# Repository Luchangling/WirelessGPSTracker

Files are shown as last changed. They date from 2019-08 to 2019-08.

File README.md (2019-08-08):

# 项目使用说明
    本项目是深圳市谷米万物科技有限公司自主研发的GW系列超长待机GPS定位器全套原理图、PCB、BOM（在/doc/硬件设计目录下）
    以及应用层源代码等，采用BSD许可协议。任何企业和个人都可以下载、使用或者修改后使用。
    
    项目基于MTK内核开发，/lib/GM_03D_OP_F1提供一个供测试使用的内核库（无法保证大规模使用），如要大规模商用可以联系
    深圳市谷米万物科技有限公司市场部人员索取正式版内核库文件和授权书（内容详见《开源授权书》），下载工具在下面的链接中给出。
    
    编译工具链接：https://pan.baidu.com/s/1ckqe6dtqmJymWbYbLE8zCg 提取码：9bxm 
    APP下载工具链接：https://pan.baidu.com/s/1FpO7Suf3HKmFG9RSkq1bLQ 提取码：pxhs
    内核下载工具链接：https://pan.baidu.com/s/13P_ccS7nhhhhS0J0DI3Q7A 提取码：p4ar 
    以上工具由热心网友提供，建议大家购买正版编译工具和下载工具
    
    测试样机：
    https://detail.m.tmall.com/item.htm?id=588600707880
    https://detail.m.tmall.com/item.htm?id=579762201357

    FAQ文档：
    https://github.com/brucewangzhihua/GPSTracker/blob/master/FAQ.txt

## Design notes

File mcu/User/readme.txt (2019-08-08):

/** @page TIM2_TRIGLSE Generate PWM signal using LSE clock source for TIM2 counter 

  @verbatim
  ******************** (C) COPYRIGHT 2013 STMicroelectronics *******************
  * @file    TIM2/TIM2_TRIGLSE/readme.txt
  * @author  MCD Application Team
  * @version V1.5.2
  * @date    30-September-2014
  * @brief   Description of the TIM2 external trigger mapped to LSE clock Example.
  ******************************************************************************
  *
  * Licensed under MCD-ST Liberty SW License Agreement V2, (the "License");
  * You may not use this file except in compliance with the License.
  * You may obtain a copy of the License at:
  *
  *        http://www.st.com/software_license_agreement_liberty_v2
  *
  * Unless required by applicable law or agreed to in writing, software 
  * distributed under the License is distributed on an "AS IS" BASIS, 
  * WITHOUT WARRANTIES OR CONDITIONS OF ANY KIND, either express or implied.
  * See the License for the specific language governing permissions and
  * limitations under the License.
  *
  ******************************************************************************
   @endverbatim

  @par Example description

  This example explains how to configure TIM2 time base that works completely 
  independently of the system clock. This allows the scheduling of tasks without
  having to take into account the processor state (the processor may be stopped 
  or executing at low or full speed).
  For this purpose, the LSE clock can be internally mapped to the TIM2 ETR input.

  Moreover, this example shows how to configure the TIM2 channel 1 in PWM 
  (Pulse Width Modulation) mode and to be clocked with the LSE clock.
  The TIM2CLK frequency is set to the ETR div 4, the counter prescaler is 1 
  so the TIM2 counter clock is LSE / 4 = 32.768 KHz / 4 = 8.192 KHz.

  The TIM2 period is set to 7, so update event is generated each (7 + 1 ) / 8.192KHz ~ 1 ms
  TIM2 Channel 1 generates a PWM signal with a frequency equal to 1.024 KHz
  TIM2 pulse is set to 4, so the TIM2 Channel 1 generates a PWM signal with 
  a duty cycle equal to 50%:
  TIM2 Channel1 duty cycle = (TIM2 Pulse / (TIM2 Period + 1)) * 100 = 100 * (4 / (7 + 1)) = 50%

  @par Directory contents

  - TIM2/TIM2_TRIGLSE/main.c            Main file containing the "main" function
  - TIM2/TIM2_TRIGLSE/stm8l15x_conf.h   Library Configuration file
  - TIM2/TIM2_TRIGLSE/stm8l15x_it.c     Interrupt routines source
  - TIM2/TIM2_TRIGLSE/stm8l15x_it.h     Interrupt routines declaration

  @par Hardware and Software environment

    - This example runs on STM8L15x High-Density, Medium-Density Plus, Medium-Density
    and Low-Density Devices.

  - This example has been tested with STMicroelectronics STM8L1528-EVAL 
    (STM8L15x High-Density devices) and STM8L1526-EVAL (STM8L15x Medium-Density and
    Low-Density devices) evaluation boards and can be easily tailored to any other
    development board.

  - STM8L1528-EVAL & STM8L1526-EVAL Set-up
    - Make sure that the LCD glass daughter board is mounted in IO position.
      For more details please refer to the evaluation board user manual.
    - Connect TIM2 Channel 1 pin (PB0) to an oscilloscope

  @par How to use it ?

  In order to make the program work, you must do the following :

  - Copy all source files from this example folder to the template folder under
    Project\STM8L15x_StdPeriph_Template
  - Open your preferred toolchain 
  - Rebuild all files and load your image into target memory
  - Run the example

 * <h3><center>&copy; COPYRIGHT STMicroelectronics</center></h3>
 */

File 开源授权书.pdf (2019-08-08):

# 授权书

兹授权： | ，可将我司遵循 BSD 许可协议的开源项

目（该项目是深圳市谷米万物科技有限公司自主研发的 GS03 和 GS05 系列 GPS

定位器全套原理图、PCB、BOM 以及应用层源代码等）应用于商业用途。

在应用我司开源项目于商业用途时，应遵循以下协议要求：

1、一切开源的技术资料包括但不限于源代码、文档、原理图、PCB 等版权

属于深圳市谷米万物科技有限公司；

2、提供的技术资料和源码不保证不存在缺陷，由此造成的一切损失由使用

者承担和负责；

3、使用者必须在产品或者产品包装显眼处标注“本产品由谷米万物提供核

心技术支持”。

授权时间： | ~

深圳市谷米万物科技有限公司（盖章）

日期：

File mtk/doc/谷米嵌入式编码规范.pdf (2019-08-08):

### 一、原则

1. 开放封闭原则：对于扩展是开放的，对于修改是封闭的 (https://www.jianshu.com/p/26c55f40edbd)
2. 单一职责原则：每一个类或者类似的代码块应该只有一个职责，所以只有一个原因会使其改变 (https://www.jianshu.com/p/636d1115eb93)
3. 接口隔离原则：接口尽量细化，同时接口中的方法尽量的少 (https://www.jianshu.com/p/21dfe31ba85b)
4. 最少知道原则：一个对象应该对其他对象保持最少的了解 (https://www.jianshu.com/p/a633e390cf14)
5. 依赖倒置原则：高层模块，低层模块，细节（实现）都应该依赖抽象（即接口） (https://www.jianshu.com/p/314b67f04e50)

## 二、规范

1. 代码文件统一采用GB2312编码，注释中可以使用中文
2. 要解决所有的warning，格式化字符串如果类型不匹配编译器要能够报warning
3. 每一个.c文件应有一个同名.h文件，用于声明需要对外公开的接口，内部需要用到的定义、声明 等放在.c文件中
4. 头文件应当职责单一，尽量少包含其他头文件
5. 头文件应向稳定的方向包含，即应当让不稳定的模块依赖稳定的模块
6. 禁止在头文件中定义变量
7. 函数非空代码行不得超过100行
8. 函数内部要对参数的合法性进行检查
9. 每个函数都要返回错误码，调用程序必须在函数返回时检查错误码
10. 标识符的命名要清晰、明了，有明确含义，使用完整的单词（除非大家基本可以理解的缩 写），尽量避免名字中出现数字编号
11. 类型的命名：大小写字母混用，单词连在一起，每个单词首字母大写
12. 文件名、变量名和函数名：单词用小写字母，每个单词直接用下划线分割
13. 变量名应使用名词或者形容词＋名词方式命名变
14. 函数命名应以函数要执行的动作命名，一般采用动词或者动词＋名词的结构，作为接口的函

### 数名以模块名作为前缀，源文件内部函数名不加前缀，并且要声明为static

15. 宏的命名采用全大写字母，单词之间加下划线，接口文件中的宏名称以GM_开头

### 16. 全局变量应增加“g_”前缀，静态变量应增加“s_”前缀，不用或者少用全局变量和

静态变量，单个文件内部可以使用static的全局变量，可以将其理解为类的私有成员变量

17. 严禁使用未经初始化的变量作为右值，所有变量都要初始化
18. 每个普通变量（整型、字符型）的定义都要考虑范围，严防溢出
19. 每个数组的定义和使用都要严防越界的发生
20. 要尽量避免隐式或者显式的类型转换，防止截断的发生或者符号的丢失
21. 不允许直接使用魔鬼数字
22. 所有的if ... else if结构应该由else子句结束 ；switch语句必须有default分支
23. 程序块采用缩进风格编写，每级缩进为4个空格
24. 相对独立的程序块之间、变量说明之后必须加空行。

25. 多个短语句（包括赋值语句）不允许写在同一行内，即一行只写一条语句
26. if、for、do、while、case、switch、default等语句独占一行
27. 在两个以上的关键字、变量、常量进行对等操作时，它们之间的操作符之前、之后或者前后 要 加空格；进行非对等操作时（如->），后面不应加空格

## 三、注释

1. 文件头部注释：头文件和源文件都要注释，可以使用中文，修改时要一并修改
1 /**
2 * Copyright © Goome Technologies Co., Ltd. 2009‐2019. All right s reserved.
3 | * File name:
4 | * Author: | Version: | Date:
5 | * Description: 用于详细说明此程序文件完成的主要功能，与其他模块或函
数
6 | 的接口，输出值、取值范围、含义及参数间的控制、顺序、独
7 | 立或依赖等关系
8 | * Others:其它内容的说明
9 | * Function List:主要函数列表，每条记录应包括函数名及功能简要说明
10 | 1. ....
11 | * History: 修改历史记录列表，包括修改日期、修改者及修改内容简述
12 | 1. Date:
13 | Author:
14 | Modification:
15 | 2. ...
16 | */
2. 函数注释：函数声明要注释，函数实现不要注释，避免两处不一致 1 /**
2 | * Function: | 函数名称
3 | * Description:函数功能、性能等的描述
4 | * Input: | 输入参数说明，包括每个参数的作用、取值说明及参数间关
系。
5 | * Output: | 对输出参数的说明。
6 | * Return: | 函数返回值的说明
7 | * Others: | 其它说明
8 | */

3. 函数内部注释：函数内部不是注释越多越好，而是变量命名和逻辑清晰，自注释最好，特殊情况 或者需要特别注意的地方才加注释，并且注释要放在代码行的上方，被注释的代码下面要加空行。

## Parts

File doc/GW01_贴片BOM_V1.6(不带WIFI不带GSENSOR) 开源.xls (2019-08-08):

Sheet: GW01 V1.6贴片BOM
 |  |  | GW01 MAIN PCBA物料清单
 |  | 项目负责人 | 邵钢 | BOM版本 | V1.6
 |  | 项目名称 | GW01 | 发行日期 | 2019-08-01
 | 货品代号 | 品名 | 规格 | 数量 | 位号
1 | GM-2302-GW0102-0N8 | PCB | GW01 V1.6/20190214/66.02*35*1.0MM/四层/绿油喷锡镀金
2 | GM-1401-STM8L151C8T6-0N8 | 单片机 | STM8L151C8T6/LQFP48 | 1 | U1
3 | GM-1401-TP2011-000 | 集成IC | TP2011/SOT23-5 | 1 | U3
4 | GM-1401-RT4812-000 | 集成IC | RT4812/TSOT-23-8 | 1 | U6
5 | GM-1401-MT2503-DVB | 基带芯片 | MT2503DV/B | 1 | U30
6 | GM-1401-A6625S-RDA | 射频功放 | RDA6625S | 1 | U300
8 | GM-1401-AT2659-AT0 | GPS | LNA 1559~1610MHz Gain=21.5dB nF=0.8dB 4.3mA | 1 | U4
9 | GM-1401-NFGM003-158 | GPS声表 | DNFH003-1580SA 封装：1109 丝印：H3 支持GPS BD GLONASS三合一 | 1 | SF701
10 | GM-1401-TEA5050-33B | LDO | 3.3V 封装SOT23-5,ETA5050V33S2F,ETA | 1 | U703
12 | GM-0502-000JB0-A00 | 贴片电阻 | 0R/±5%/1/20W/0201 | 4 | R62,R70,L301,R21
13 | GM-0502-330JA0-A00 | 贴片电阻 | 33R/±5%/1/20W 0201 | 2 | R711,R712
14 | GM-0502-101JA0-A00 | 贴片电阻 | 100R/±5%/1/20W/0201 | 5 | R2,R9,R71,R72,R81
15 | GM-0502-511JA0-A00 | 贴片电阻 | 510R/±5%/1/20W/0201 | 1 | R63
16 | GM-0502-102JA0-A00 | 贴片电阻 | 1K/±5% /1/20W 0201 | 7 | R1,R12,R22,R210,R305,R306,R307
17 | GM-0502-152JA0-A00 | 贴片电阻 | 1.5K ±5% 1/20W 0201 | 1 | R221
18 | GM-0502-332JA0-A00 | 贴片电阻 | 3.3K/±5%/1/20W 0201 | 1 | R10
19 | GM-0502-472JA0-A00 | 贴片电阻 | 4.7K/±5%/1/20W/0201 | 3 | R64，R233,R242
20 | GM-0502-562JA0-A00 | 贴片电阻 | 5.6K/±5%/1/20W/0201 | 1 | R15
21 | GM-0502-103JA0-A00 | 贴片电阻 | 10K/±5%/1/20W/0201 | 7 | R60,R61,R65,R101,R209,R308,R709,
22 | GM-0502-203JA0-A00 | 贴片电阻 | 20K/±5%/1/20W/0201 | 2 | R11,R47
23 | GM-0502-243JA0-A00 | 贴片电阻 | 24K/±5%/1/20W 0201 | 1 | R310
24 | GM-0502-393JA0-A00 | 贴片电阻 | 39K/±5%/1/20W 0201 | 1 | R5
26 | GM-0502-913JA0-A00 | 贴片电阻 | 91K ±5% 1/20W 0201 | 1 | R714
27 | GM-0502-104JA0-A00 | 贴片电阻 | 100K/±5%/1/20W 0201 | 4 | R76,R80,R82,R703
28 | GM-0502-104FB0-B00 | 贴片精密电阻 | 100K/±1%/1/16W/0402 | 1 | R78
29 | GM-0502-334FA0-A00 | 贴片精密电阻 | 330K/1%/1/20W 0201 | 1 | R7
30 | GM-0502-7323FB0-B00 | 贴片精密电阻 | 732K/±1%/1/16W/0402 | 1 | R77
31 | GM-0502-124JA0-A00 | 贴片电阻 | 120K ±5% 1/20W 0201 | 1 | R713
32 | GM-0502-105JA0-A00 | 贴片电阻 | 1M/±5%/1/20W/0201 | 1 | R79
33 | GM-0502-565JA0-A00 | 贴片电阻 | 5.6M/±5%/1/20W/0201 | 1 | R68
34 | GM-0502-106JA0-A00 | 贴片电阻 | 10M/±5%/1/20W/0201 | 2 | R66,R67
35 | GM-0602-60FD8B-A05 | 贴片电容 | 6PF/±0.5PF/50V/NPO/0201 | 2 | C3,C68
36 | GM-0602-180J8A-A00 | 贴片电容 | 18pF±5% /50V COG 0201 | 5 | C66,C88,C16,C703,C706
37 | GM-0602-05FC8A-A00 | 贴片电容 | 0.5pF±0.25pF 50V COG 0201 | 1 | L303
38 | GM-0602-12FC8A-A00 | 贴片电容 | 1.2pF±0.25pF 50V COG 0201 | 2 | C339,C724
39 | GM-0602-22FC8A-A00 | 贴片电容 | 2.2pF ±0.25pF 50V COG 0201 | 1 | C332
40 | GM-0602-39FC8A-A00 | 贴片电容 | 3.9PF±0.25PF 50V COG 0201 | 1 | C330
42 | GM-0602-220J8A-A00 | 贴片电容 | 22PF±5% 50V COG 0201 | 4 | C308,C309,C310,C312
43 | GM-0602-330J8A-A00 | 贴片电容 | 33PF±5% 50V COG 0201 | 5 | C1,C2,C7,C316,C342
44 | GM-0602-101J6A-A00 | 贴片电容 | 100pF±5% 25V COG 0201 | 1 | C317
45 | GM-0602-221K8A-A00 | 贴片电容 | 220pF±10% 50V COG 0201 | 1 | C307
46 | GM-0602-221K8D-A00 | 贴片电容 | 220pF±10% 50V X7R 0201
47 | GM-0602-151J8B-B05 | 贴片电容 | 150PF/±5%/50V/NPO/0402 | 1 | C19
48 | GM-0602-511J8B-C05 | 贴片电容 | 510PF/±5%/50V/NPO/0603 | 1 | C30
49 | GM-0602-104K3C-A00 | 贴片电容 | 100NF±10% 10V X5R 0201 | 9 | C12,C21,C22,C35,C60,C62,C65,C67,C732
50 | GM-0602-104M3C-A00 | 贴片电容 | 100NF±20% 10V X5R 0201
51 | GM-0602-102K6D-A00 | 贴片电容 | 1nF±10% 25V X7R 0201 | 4 | C31,C338,C709,C315
52 | GM-0602-102M8D-A00 | 贴片电容 | 1nF±20% 50V X7R 0201
53 | GM-0602-472K4D-A00 | 贴片电容 | 4.7nF±10% 16V X7R 0201 | 3 | C14,C716,C717
54 | GM-0602-104K4C-B05 | 贴片电容 | 100NF/±10%/16V/X5R/0402 | 1 | C6
55 | GM-0602-105K4C-C05 | 贴片电容 | 1UF/±10%/16V/X5R/0603 | 1 | C70
56 | GM-0602-105K2C-A00 | 贴片电容 | 1uF±10% 6.3V X5R 0201 | 33 | C5,C8,C9,C18,C34,C61,C63,C64,C69,C200,C203，C206,C207,C215,C217,C219,C223,C301,C718,C719,C720,C729,C733,C220,C727，C208,C216,C221,C224,C218,C225,C222,C711
57 | GM-0602-105M2C-A00 | 贴片电容 | 1uF±20% 6.3V X5R 0201
58 | GM-0602-225M3C-B00 | 贴片电容 | 2.2uF±20% X5R 10V 0402 | 3 | C205,C728,C730
59 | GM-0602-225M2C-B00 | 贴片电容 | 2.2uF±20% X5R 6.3V 0402
60 | GM-0602-475M2C-B00 | 贴片电容 | 4.7uF±20% X5R 6.3V 0402 | 5 | C213,C721,C722,C723,C726
61 | GM-0602-106K8C-D05 | 贴片电容 | 10UF/±10%/16V/X5R/0805 | 2 | C15,C313
62 | GM-0602-226K2C-D00 | 贴片电容 | 22uF±10% X5R 6.3V 0805 H=0.85mm | 1 | C20
63 | GM-0601-227M20-J07 | 贴片钽电容 | TLJB227M006R0500/220UF/±20%/6.3V/B型 | 2 | EC3,EC2
64 | GM-1100-LMB340-000 | 贴片二极管 | LMBR340/SOD-123 | 1 | D1
65 | GM-1501-000805-000 | 贴片发光二极管 | 白发黄/0805/SMD | 1 | LGPS
66 | GM-1501-G00805-000 | 贴片发光二极管 | 白发绿/0805/SMD | 1 | LGSM
68 | GM-0703-472MD0-006 | 贴片叠层电感 | 4.7uH±20% 0805 500mA | 1 | L707
69 | GM-0701-24FSA0-004 | 贴片叠层电感 | 2.4nH ±0.3NH 0201 | 1 | C328
70 | GM-0701-30FSA0-004 | 贴片电感 | 3.0nH±0.3nH 0201 | 1 | L309
71 | GM-0701-33FSA0-004 | 贴片叠层电感 | 3.3nH ±0.3NH 0201 | 1 | L702
72 | GM-0701-36FSA0-004 | 贴片电感 | 3.6nH±0.3nH 0201 | 2 | C340,C343
73 | GM-0701-47FSA0-004 | 贴片叠层电感 | 4.7nH ±0.3NH 0201 | 1 | C306
74 | GM-0701-68FJA0-004 | 贴片电感 | 6.8NH±5% 0201 | 3 | L2,C318,L308
75 | GM-0701-100JA0-004 | 贴片电感 | 10nH ±5% 0201 | 1 | L4
76 | GM-0701-270JA0-004 | 贴片电感 | 27NH±5% 0201 | 1 | L320
77 | GM-0701-390JA0-004 | 贴片电感 | 39nH±5% 0201 | 1 | C701
79 | GM-0703-152M90-0MT | 贴片电感 | 1.5UH/±20%/7.6*7.0*3.0MM/一体成型/SMD | 1 | L1
80 | GM-1200-L9014Q-001 | 贴片三极管 | L9014QLT1G/SOT-23 | 1 | Q5
81 | GM-1201-SI2305-001 | 贴片MOS管 | SI2305DS/SOT23 | 2 | Q2,Q4
82 | GM-1201-NC3416-001 | 贴片MOS管 | NCE3416/SOT-23 | 1 | Q3
83 | GM-2200-SC32S0-0JG | 贴片晶振 | 32.768khz/3215/12.5 pF/ Q-SC32S03220C5AAAF， | 1 | Y1
84 | GM-2200-X1G004-EPS | 贴片晶振 | 26MHz ±0.5ppm 2520 TCXO 丝印J5，X1G004211000300，EPSON | 1 | Y702
89 | GM-2200-X3S026-HEL | 贴片晶振 | 26MHZ 3.2*2.5mm，X3S026000B71HZ-HPR，加高 | 1 | X301
96 | GM-5303-GW0102-00X | 基带屏蔽罩 | 洋白铜，36*31*2.0mm,GW01基带屏蔽罩,鼎宇五金 | 1
97 | GM-2118-YK56SL-000 | 拨动开关 | YK56-SL（大六角）柄高2.0mm，间距2.5mm/耐高温 | 1 | K1
98 | GM-5416-GW01PG-JXX | 贴片天线顶针 | PG6.7-4.7 Φ=2.0 H=2.0mm | 1 | RF3
99 | GM-2101-1*4PIN-000 | 贴片插座 | 1*4PIN，间距1.0mm/L6.0*H4.5*W3.0mm | 1 | CON1
100 | GM-2105-UPC791-MUP | SIM卡座 | 8PIN Micro-sim Card con,MUP-C791,H=1.5mm | 1 | SIM1

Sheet: 修改记录
日期 | 版本号 | 更改序号 | 更 改 内 容 | 更改人 | 备注

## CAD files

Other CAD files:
mcu/STVP/stvp_download.stp

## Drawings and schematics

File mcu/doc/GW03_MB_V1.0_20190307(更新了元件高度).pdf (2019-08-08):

A

1 | 2 | 3 | 4 | 5 | 6

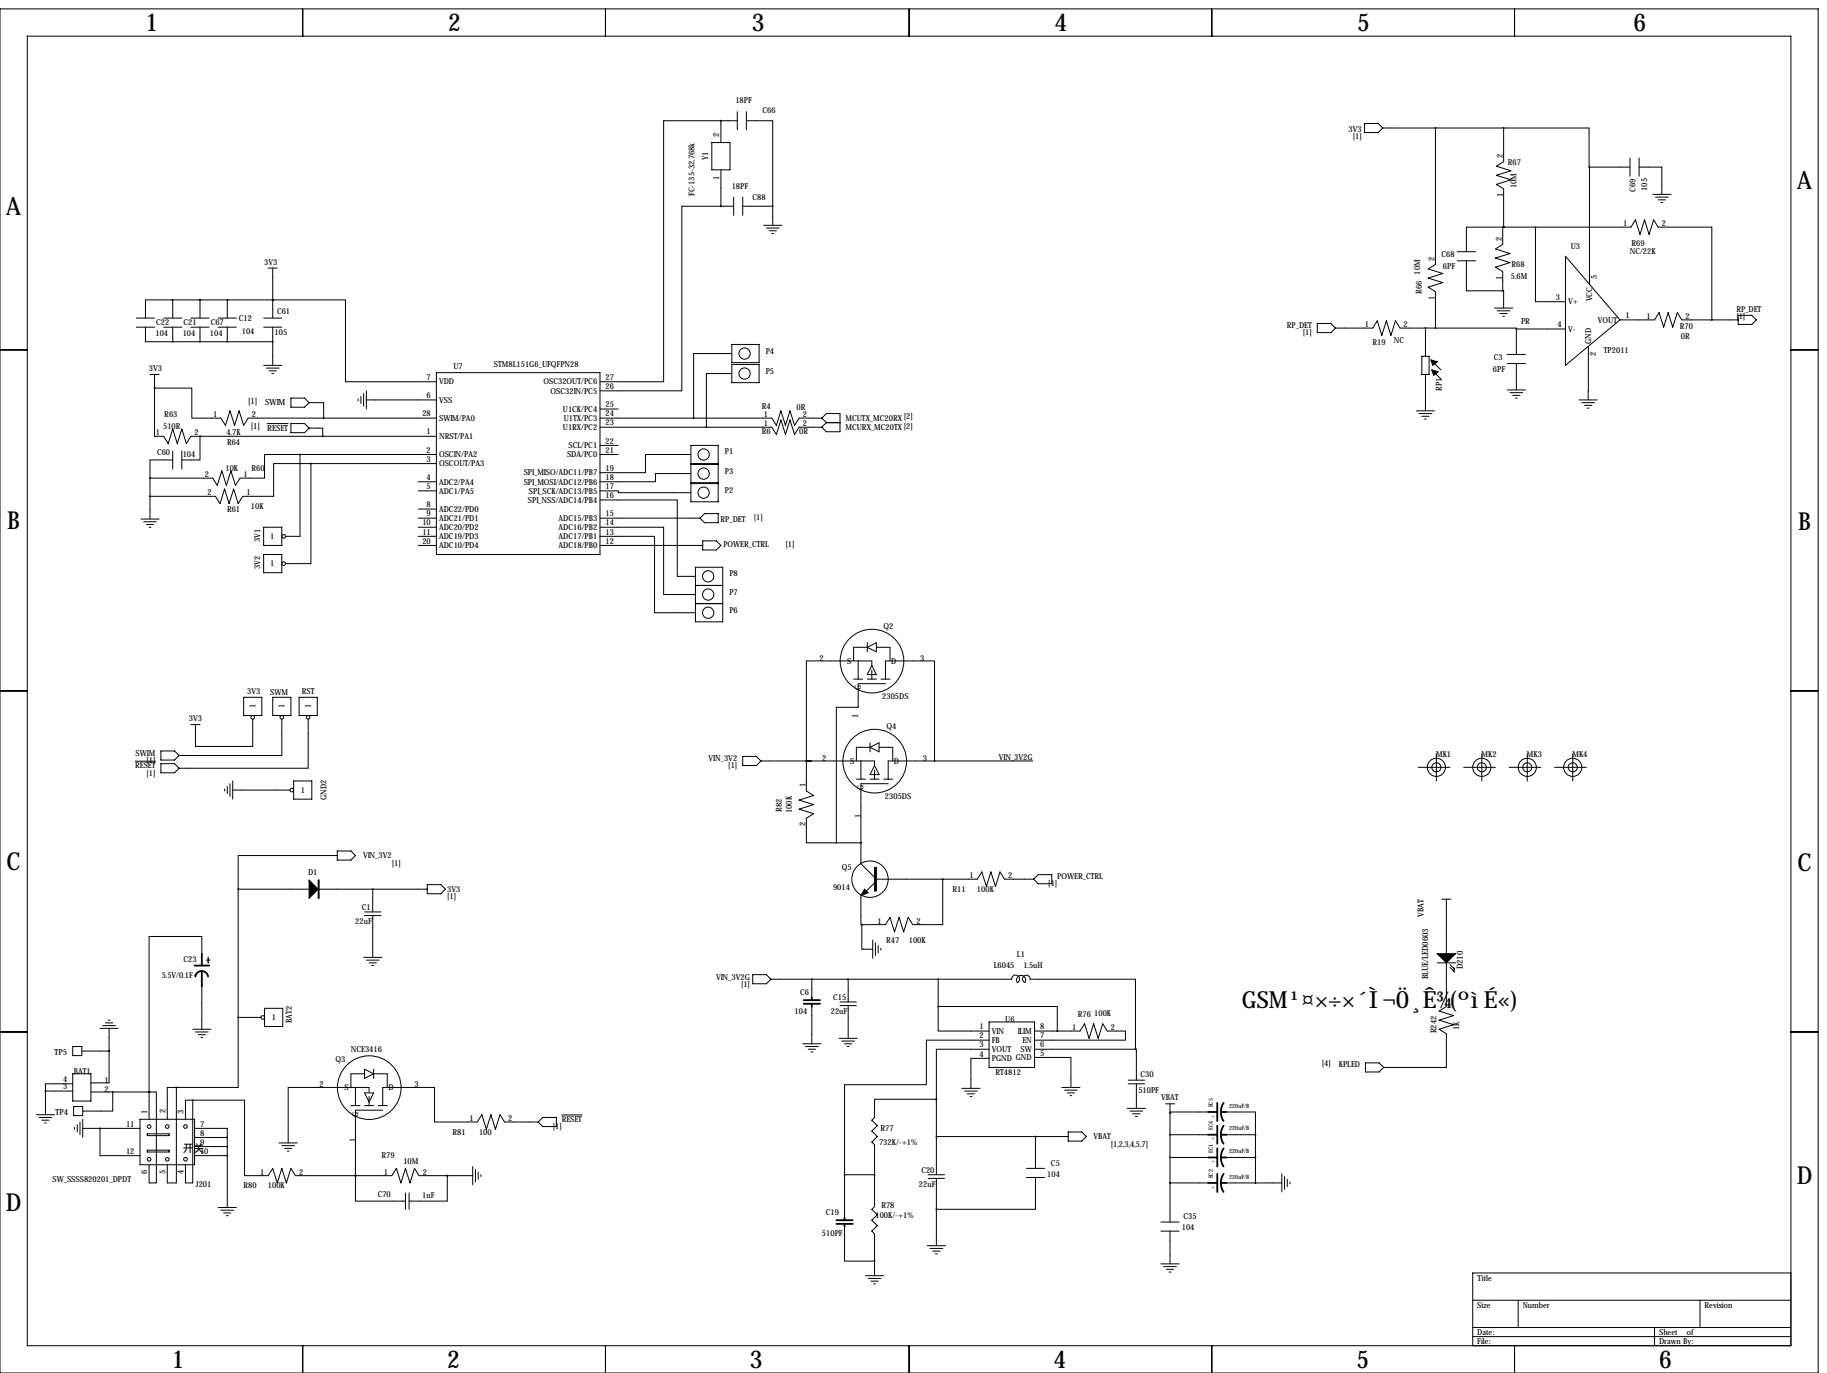
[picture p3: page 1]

OSCIN/PA2 3

ADC2/PA4 5 ADC22/PD0 9

Size | Number | Revision

Date: | Sheet of
File: | Drawn By:

6 | 5 | 4 | 3 | 2 | 1

D

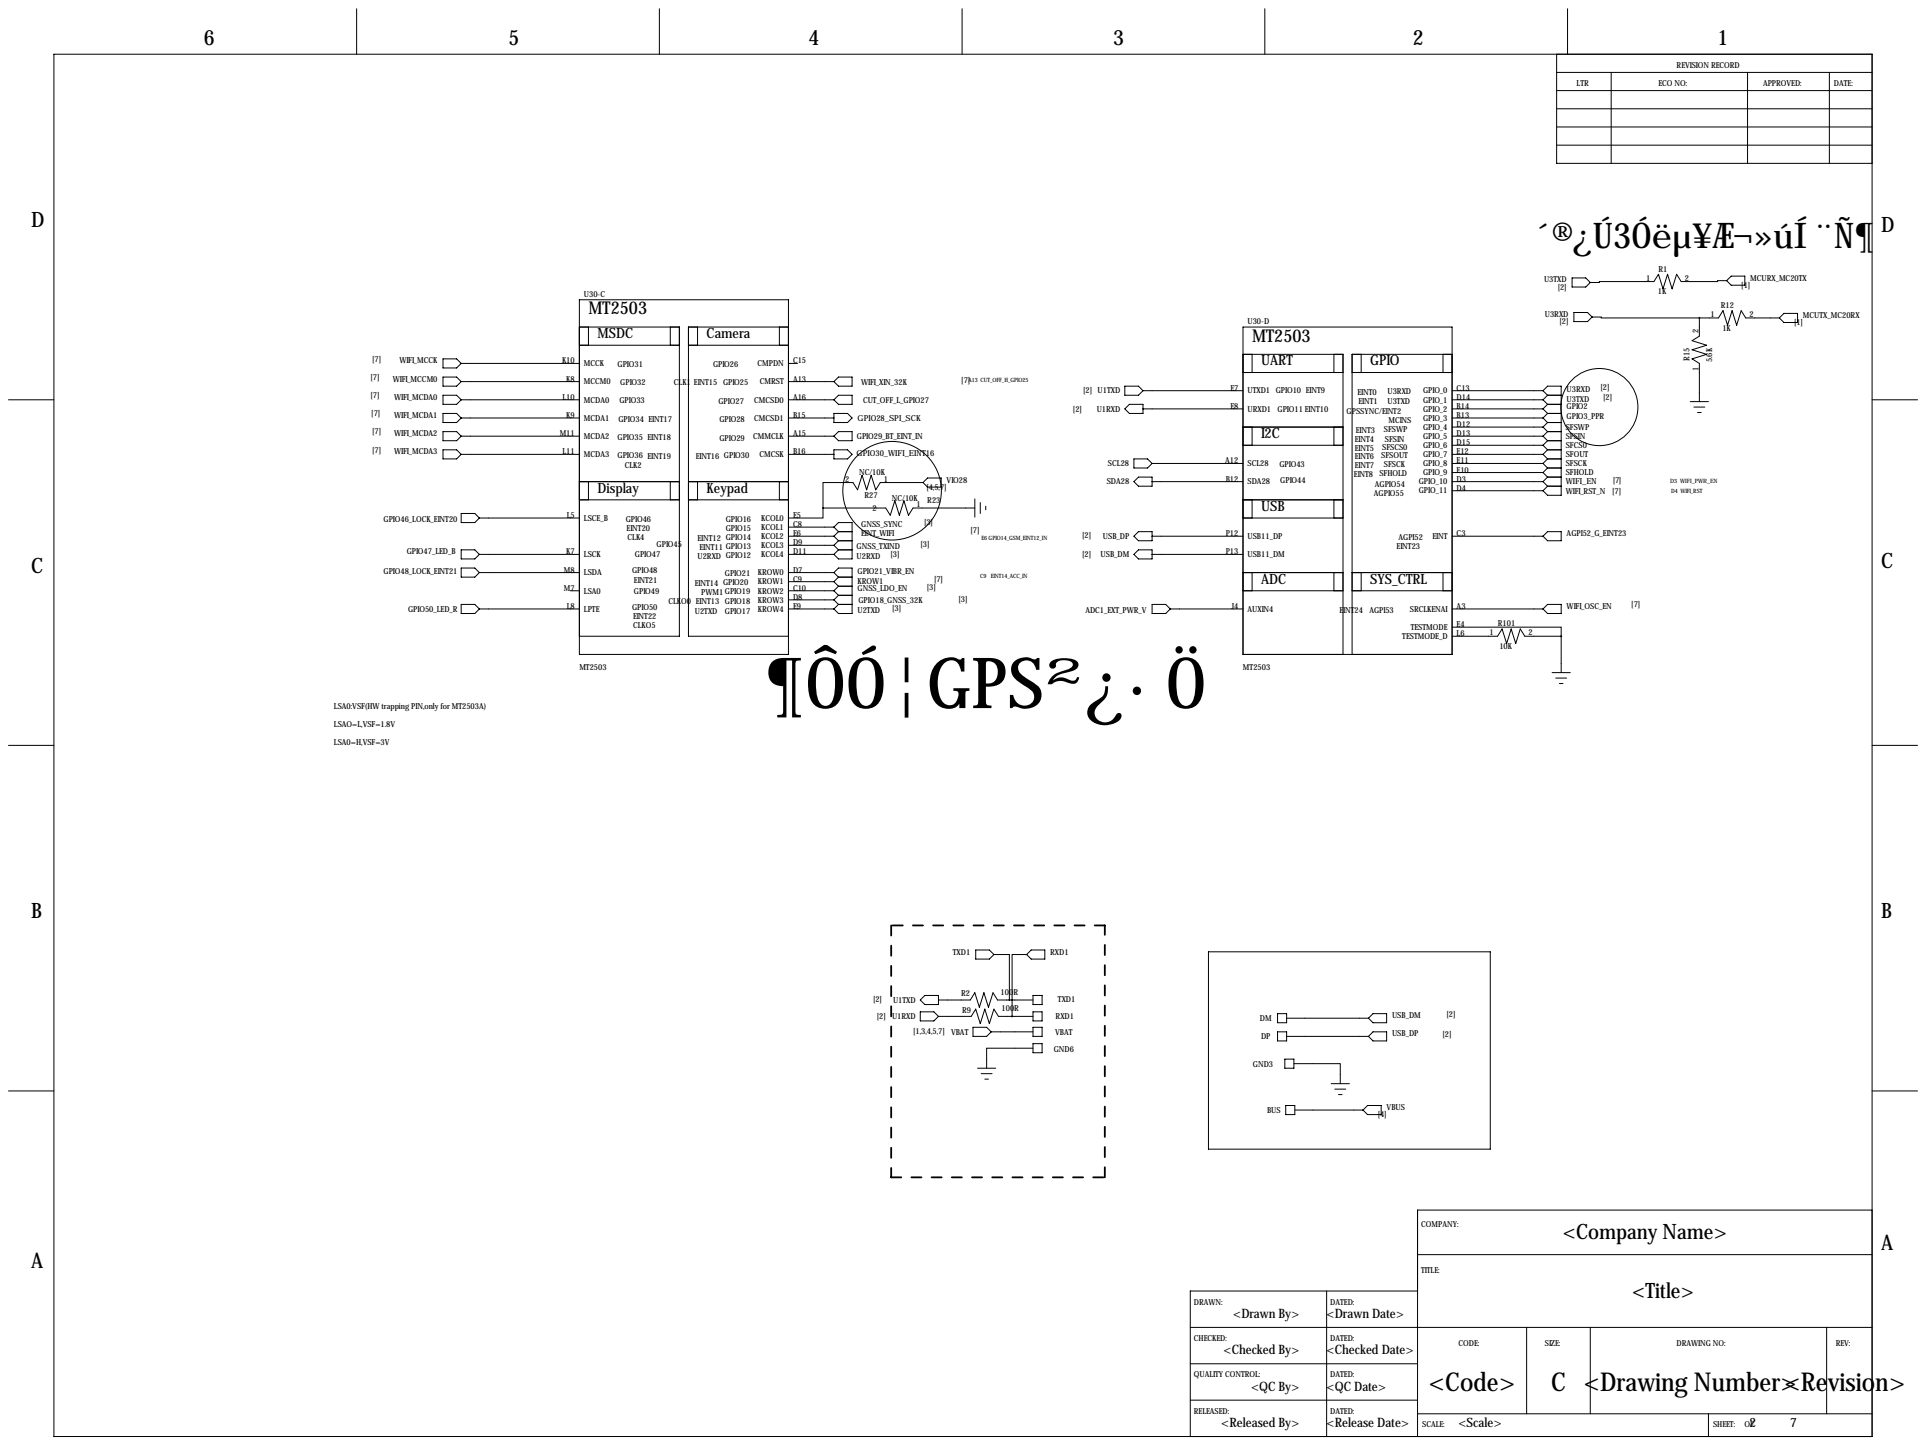
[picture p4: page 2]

U30-C | REVISION RECORD

LTR | ECO NO: | APPROVED: | DATE:

LSA0:VSF(HW trapping PIN,only for MT2503A)

DRAWN: <Drawn By> | DATED: <Drawn Date>

CHECKED: <Checked By> | DATED: <Checked Date> | CODE: | SIZE: | DRAWING NO: | REV:

QUALITY CONTROL: <QC By> | DATED: <QC Date>

RELEASED: <Released By> | DATED: <Release Date>

<Scale> SCALE: | 2 7 SHEET: OF

D
D

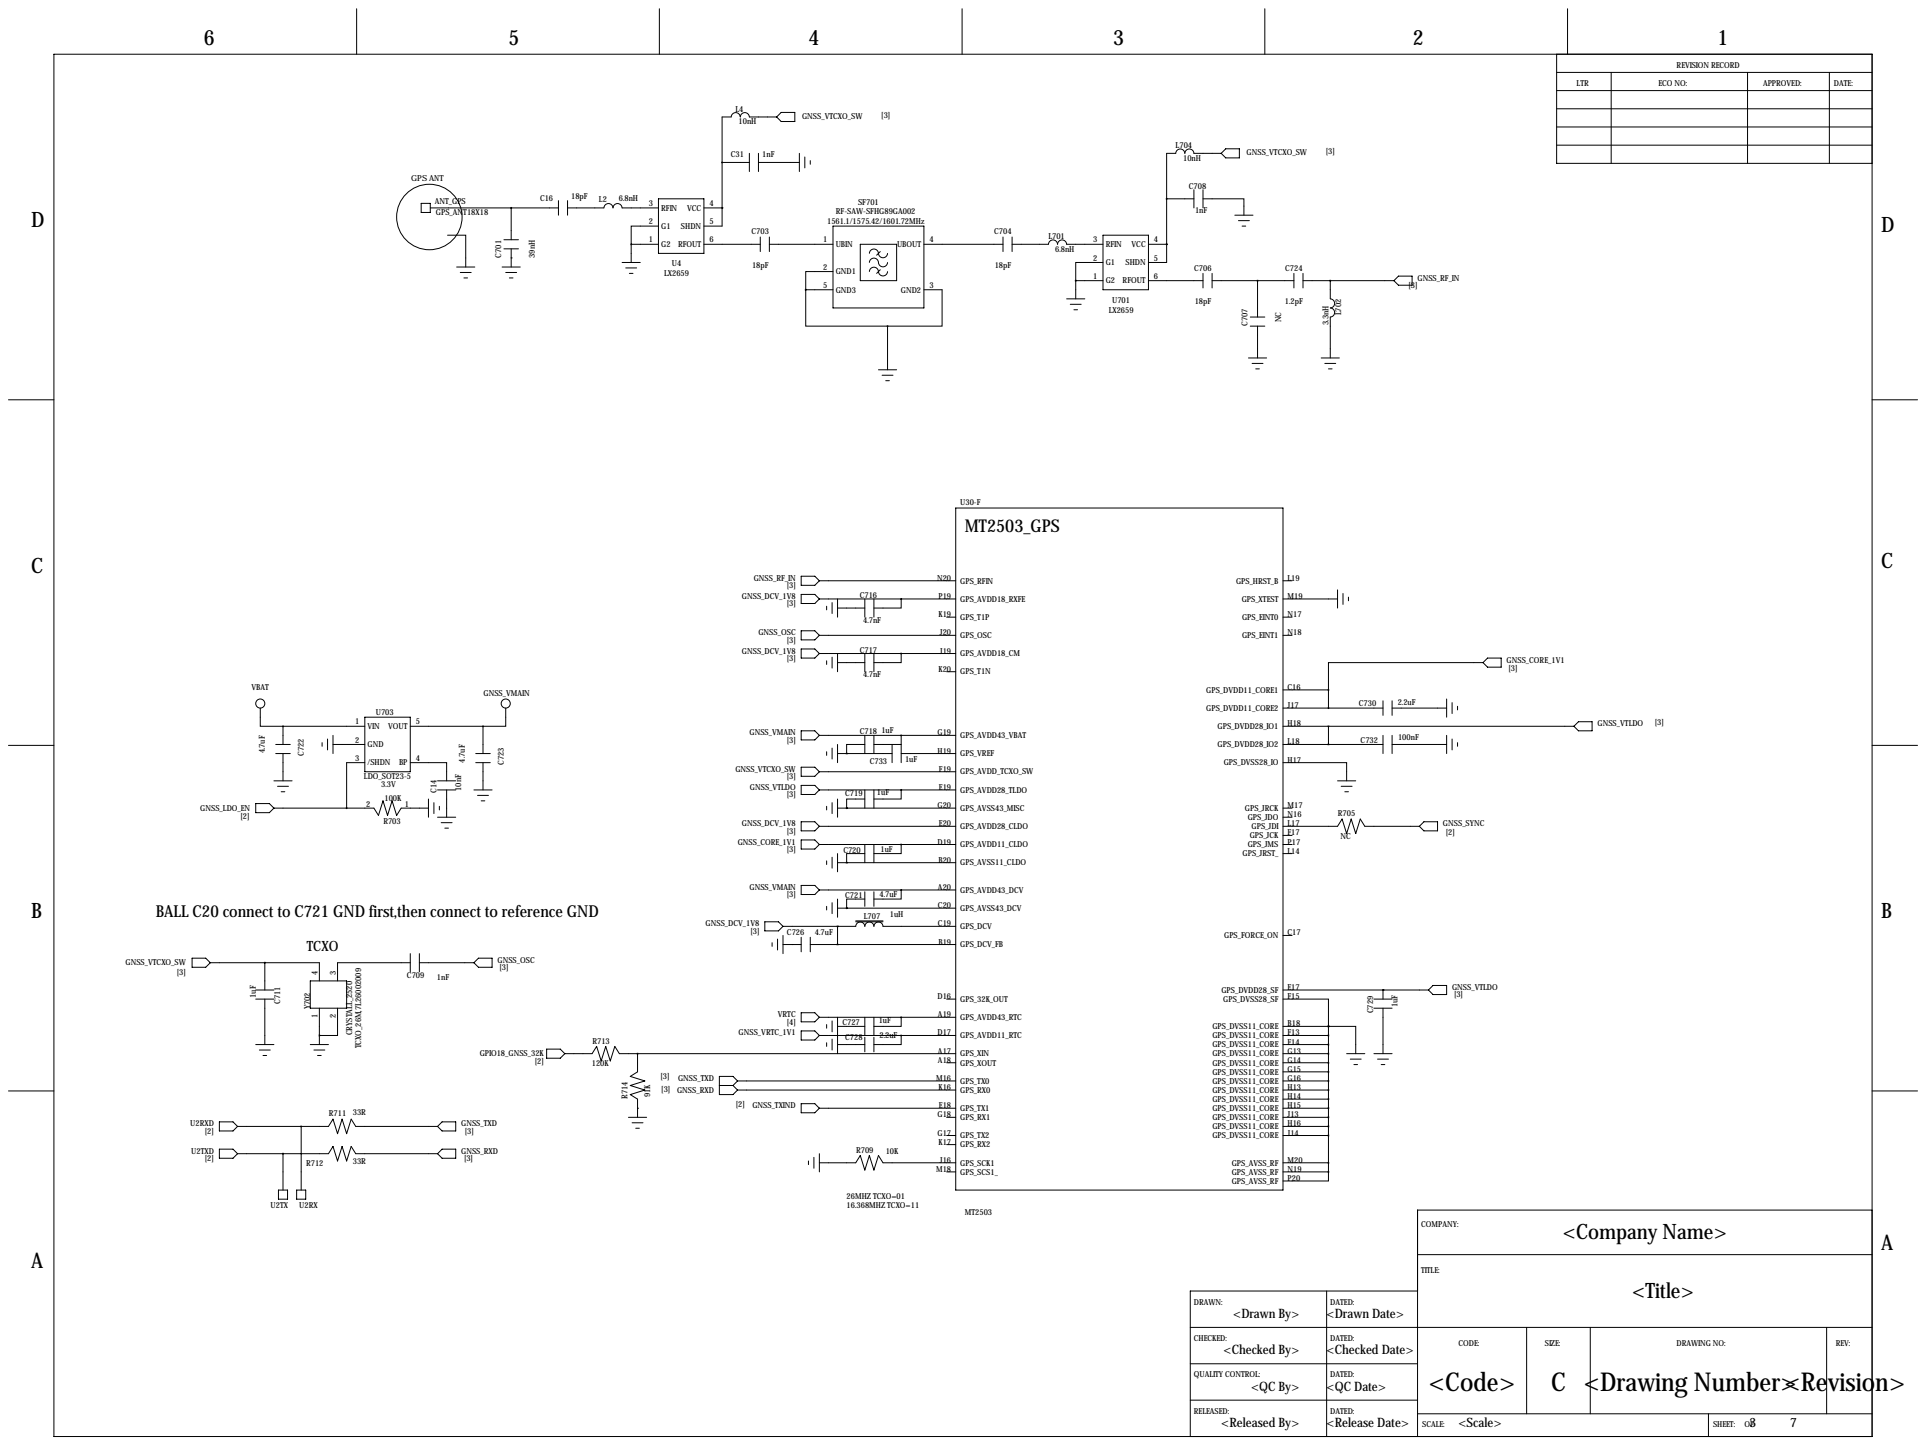
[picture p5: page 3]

BALL C20 connect to C721 GND first,then connect to reference GND

F13 GPS_DVSS11_CORE

C728 | 2.2uF | F14 GPS_DVSS11_CORE

DRAWN: <Drawn By> | DATED: <Drawn Date>

CHECKED: | DATED: | CODE: | SIZE: | DRAWING NO: | REV:

D
D

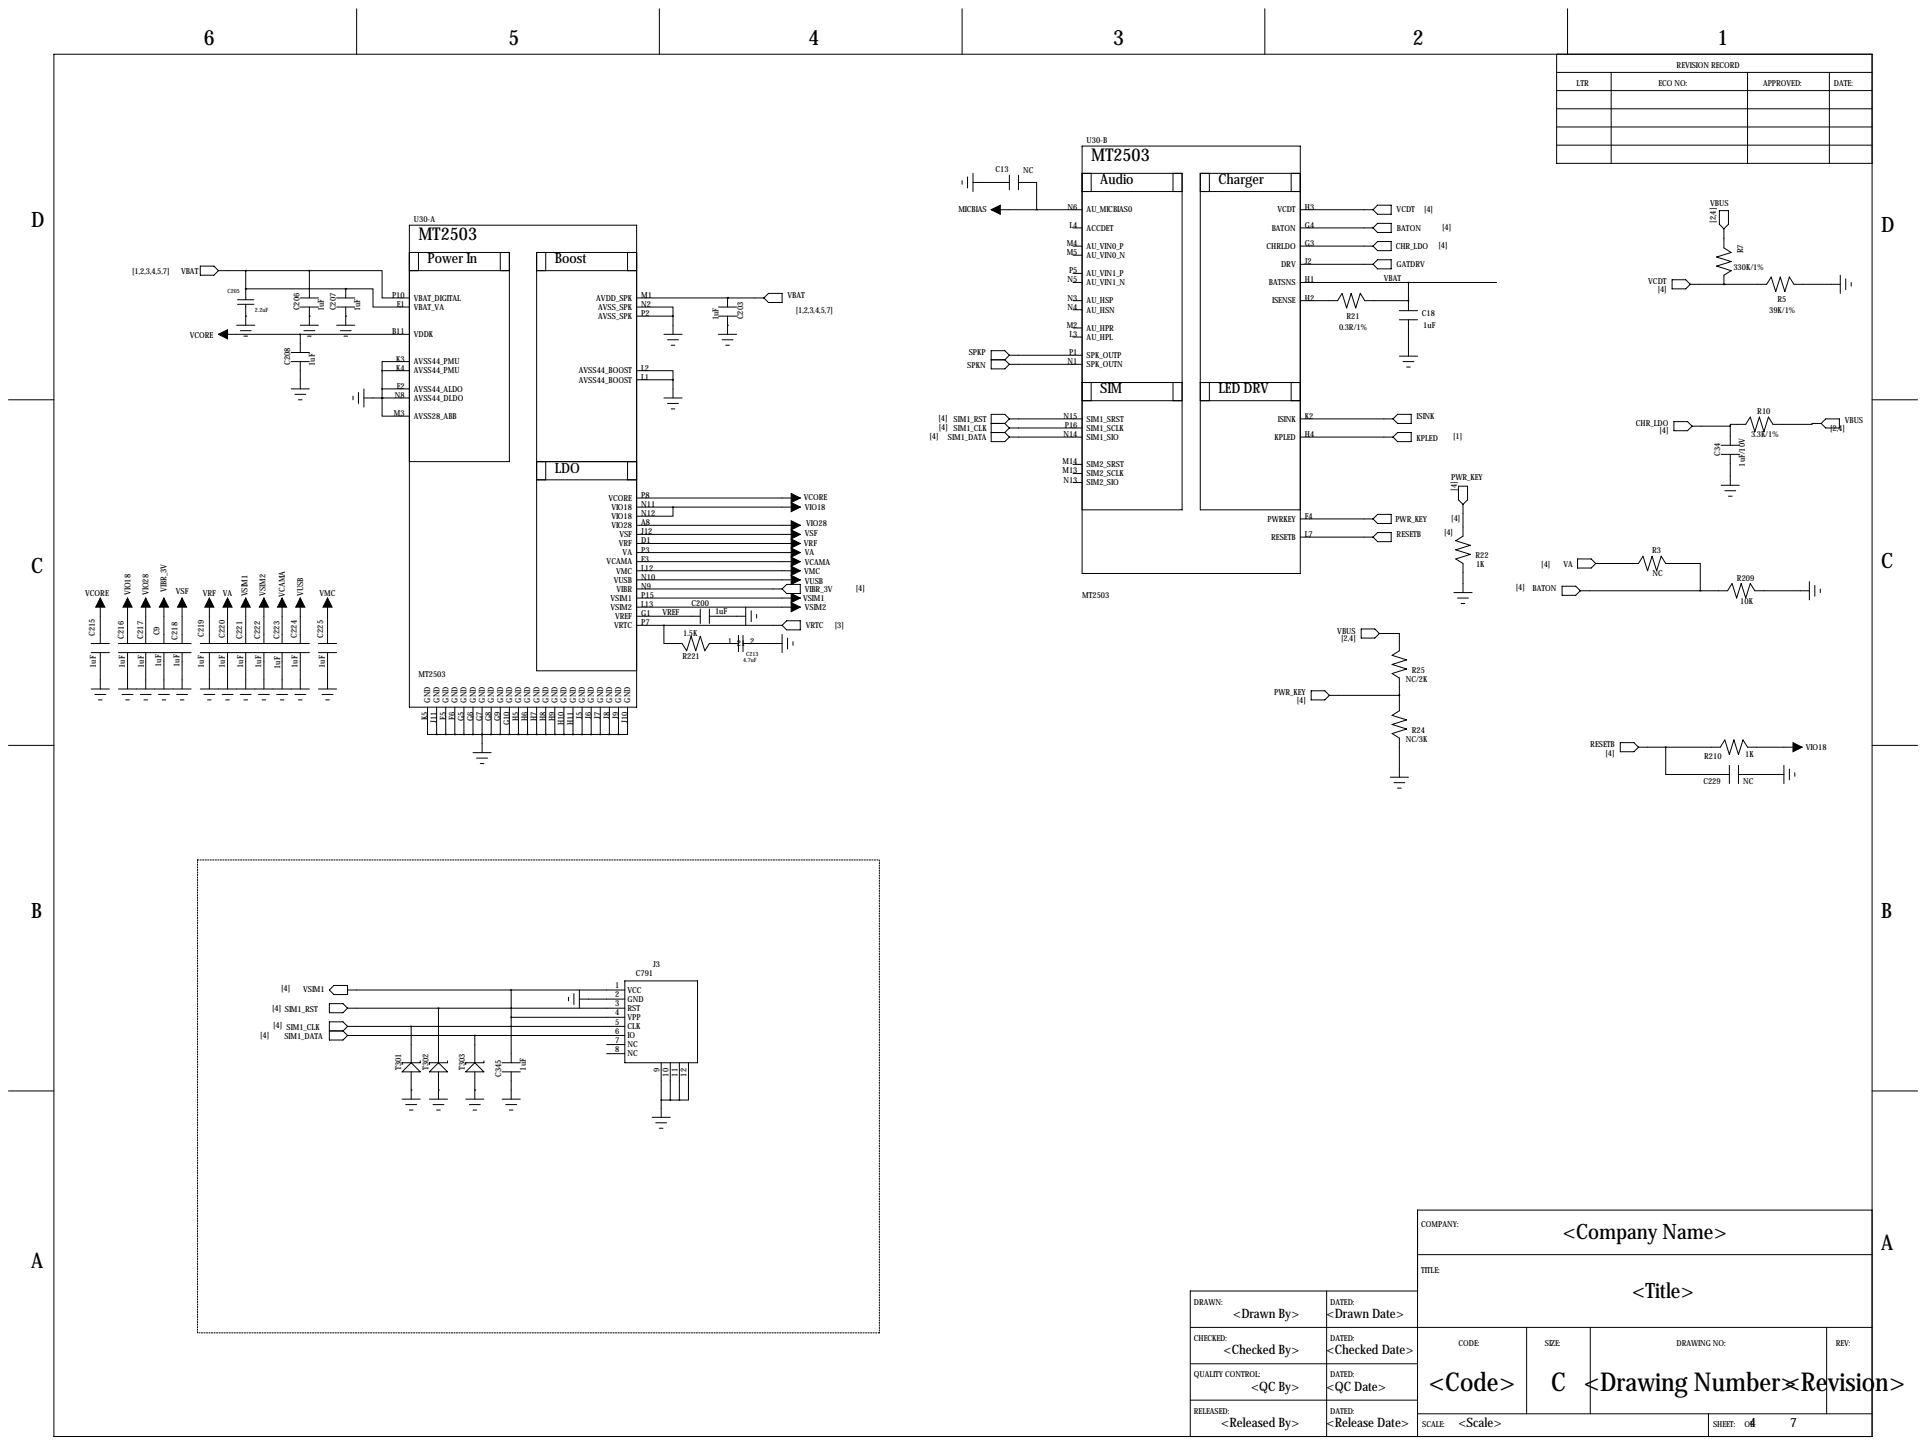
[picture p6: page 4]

CLK 6
IO 7

DRAWN: <Drawn By> | DATED: <Drawn Date>

CHECKED: | DATED: | CODE: | SIZE: | DRAWING NO: | REV:

D
D

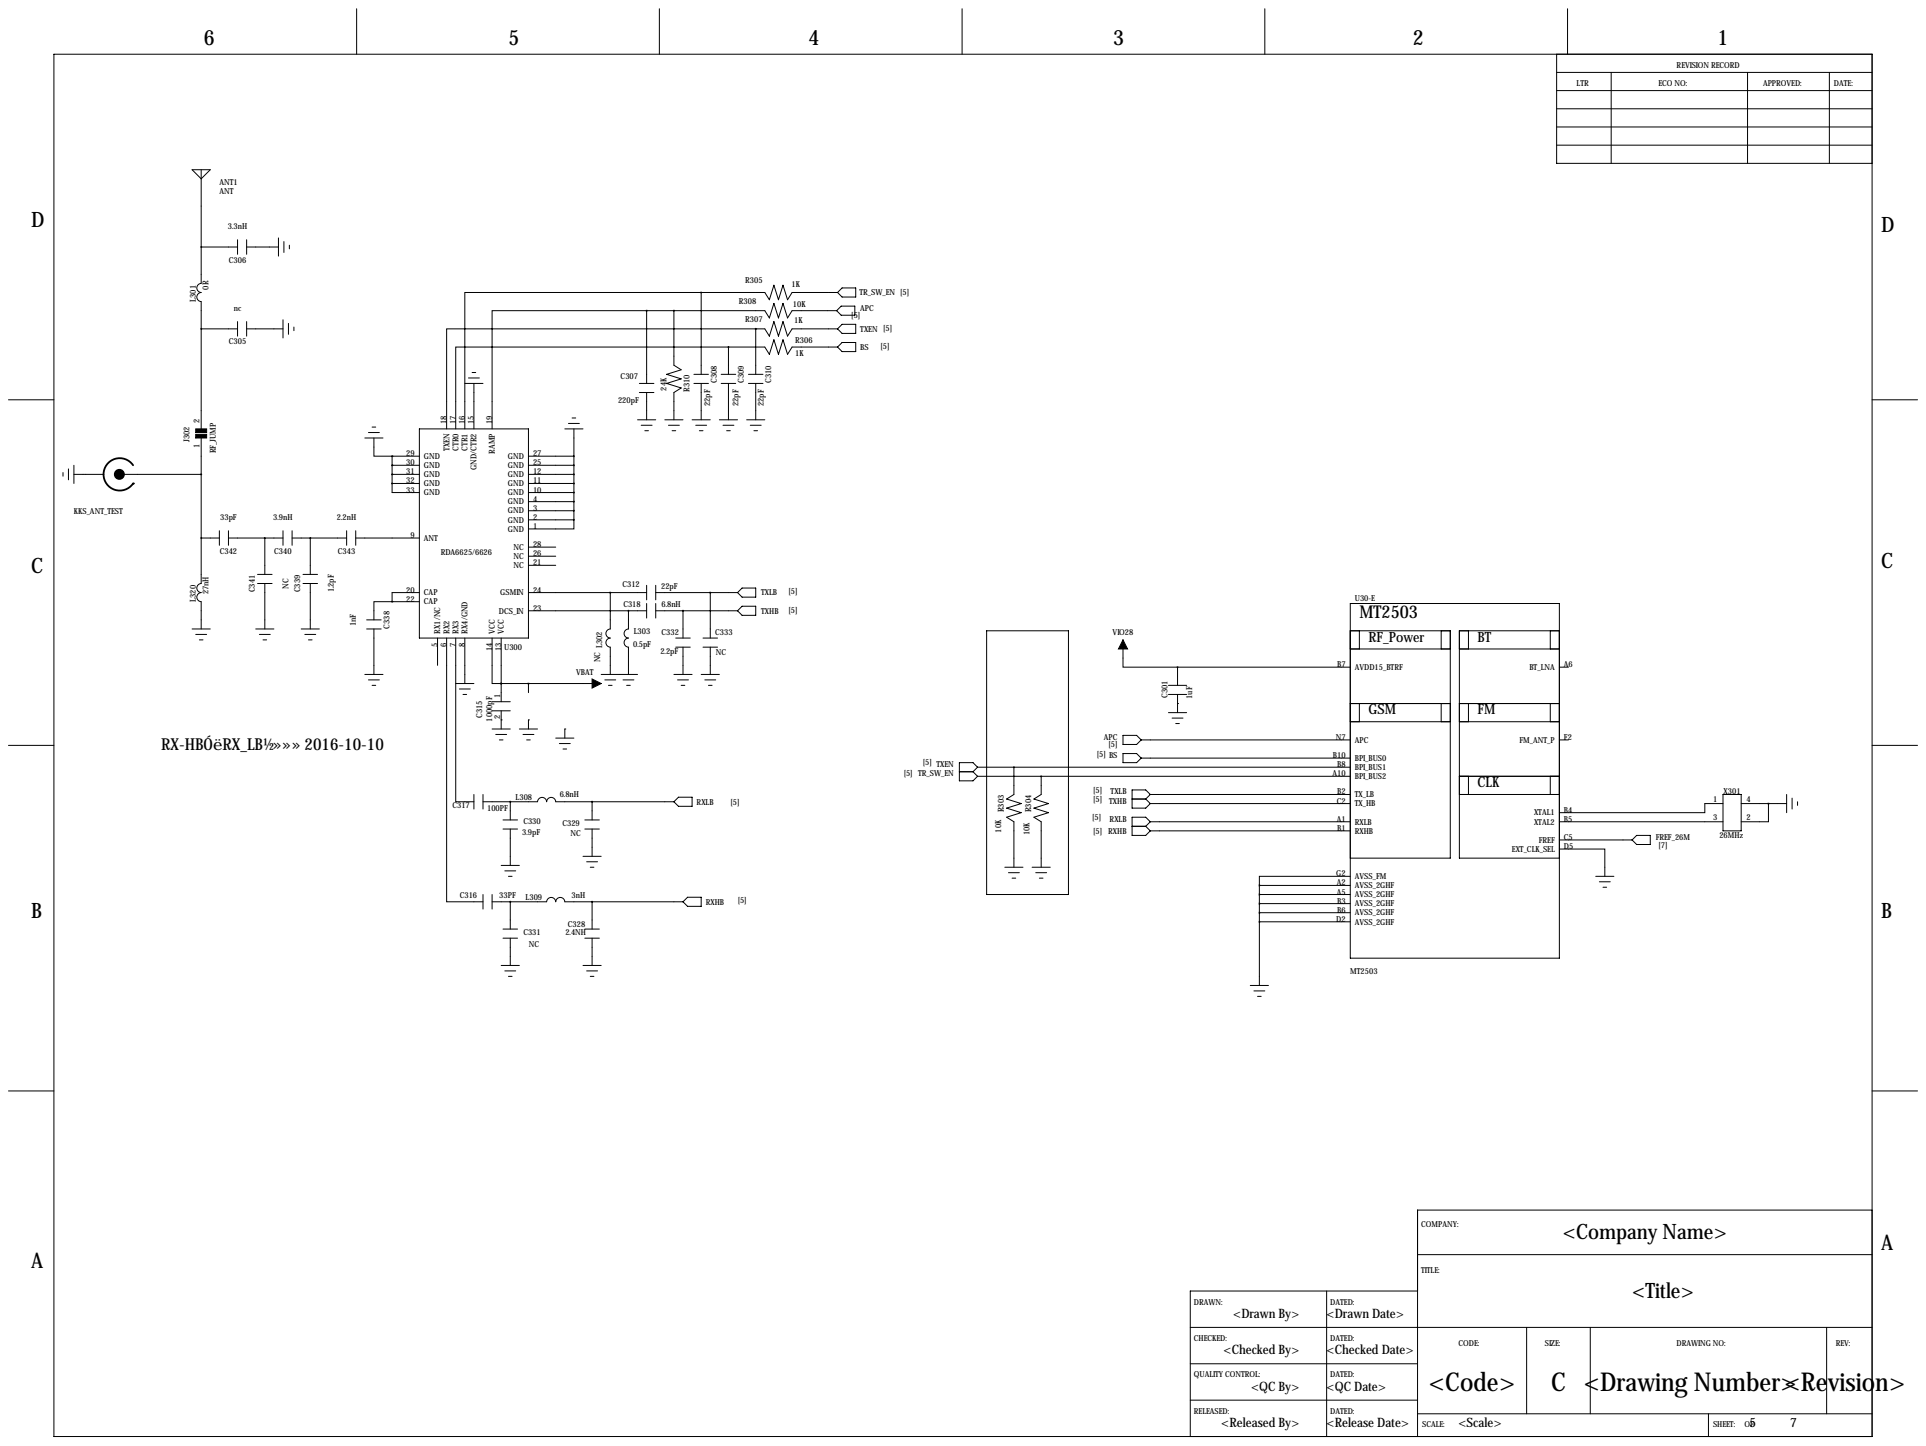
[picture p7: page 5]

DRAWN: <Drawn By> | DATED: <Drawn Date>

CHECKED: | DATED: | CODE: | SIZE: | DRAWING NO: | REV:

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
LTR | ECO NO: | APPROVED: | DATE:

TITLE:

COMPANY:

DRAWN: <Drawn By> | DATED: <Drawn Date>
CHECKED: | DATED: | CODE: | SIZE: | DRAWING NO: | REV:
<Scale> | 6 | 7

# <Title>

# <Company Name>

D

D

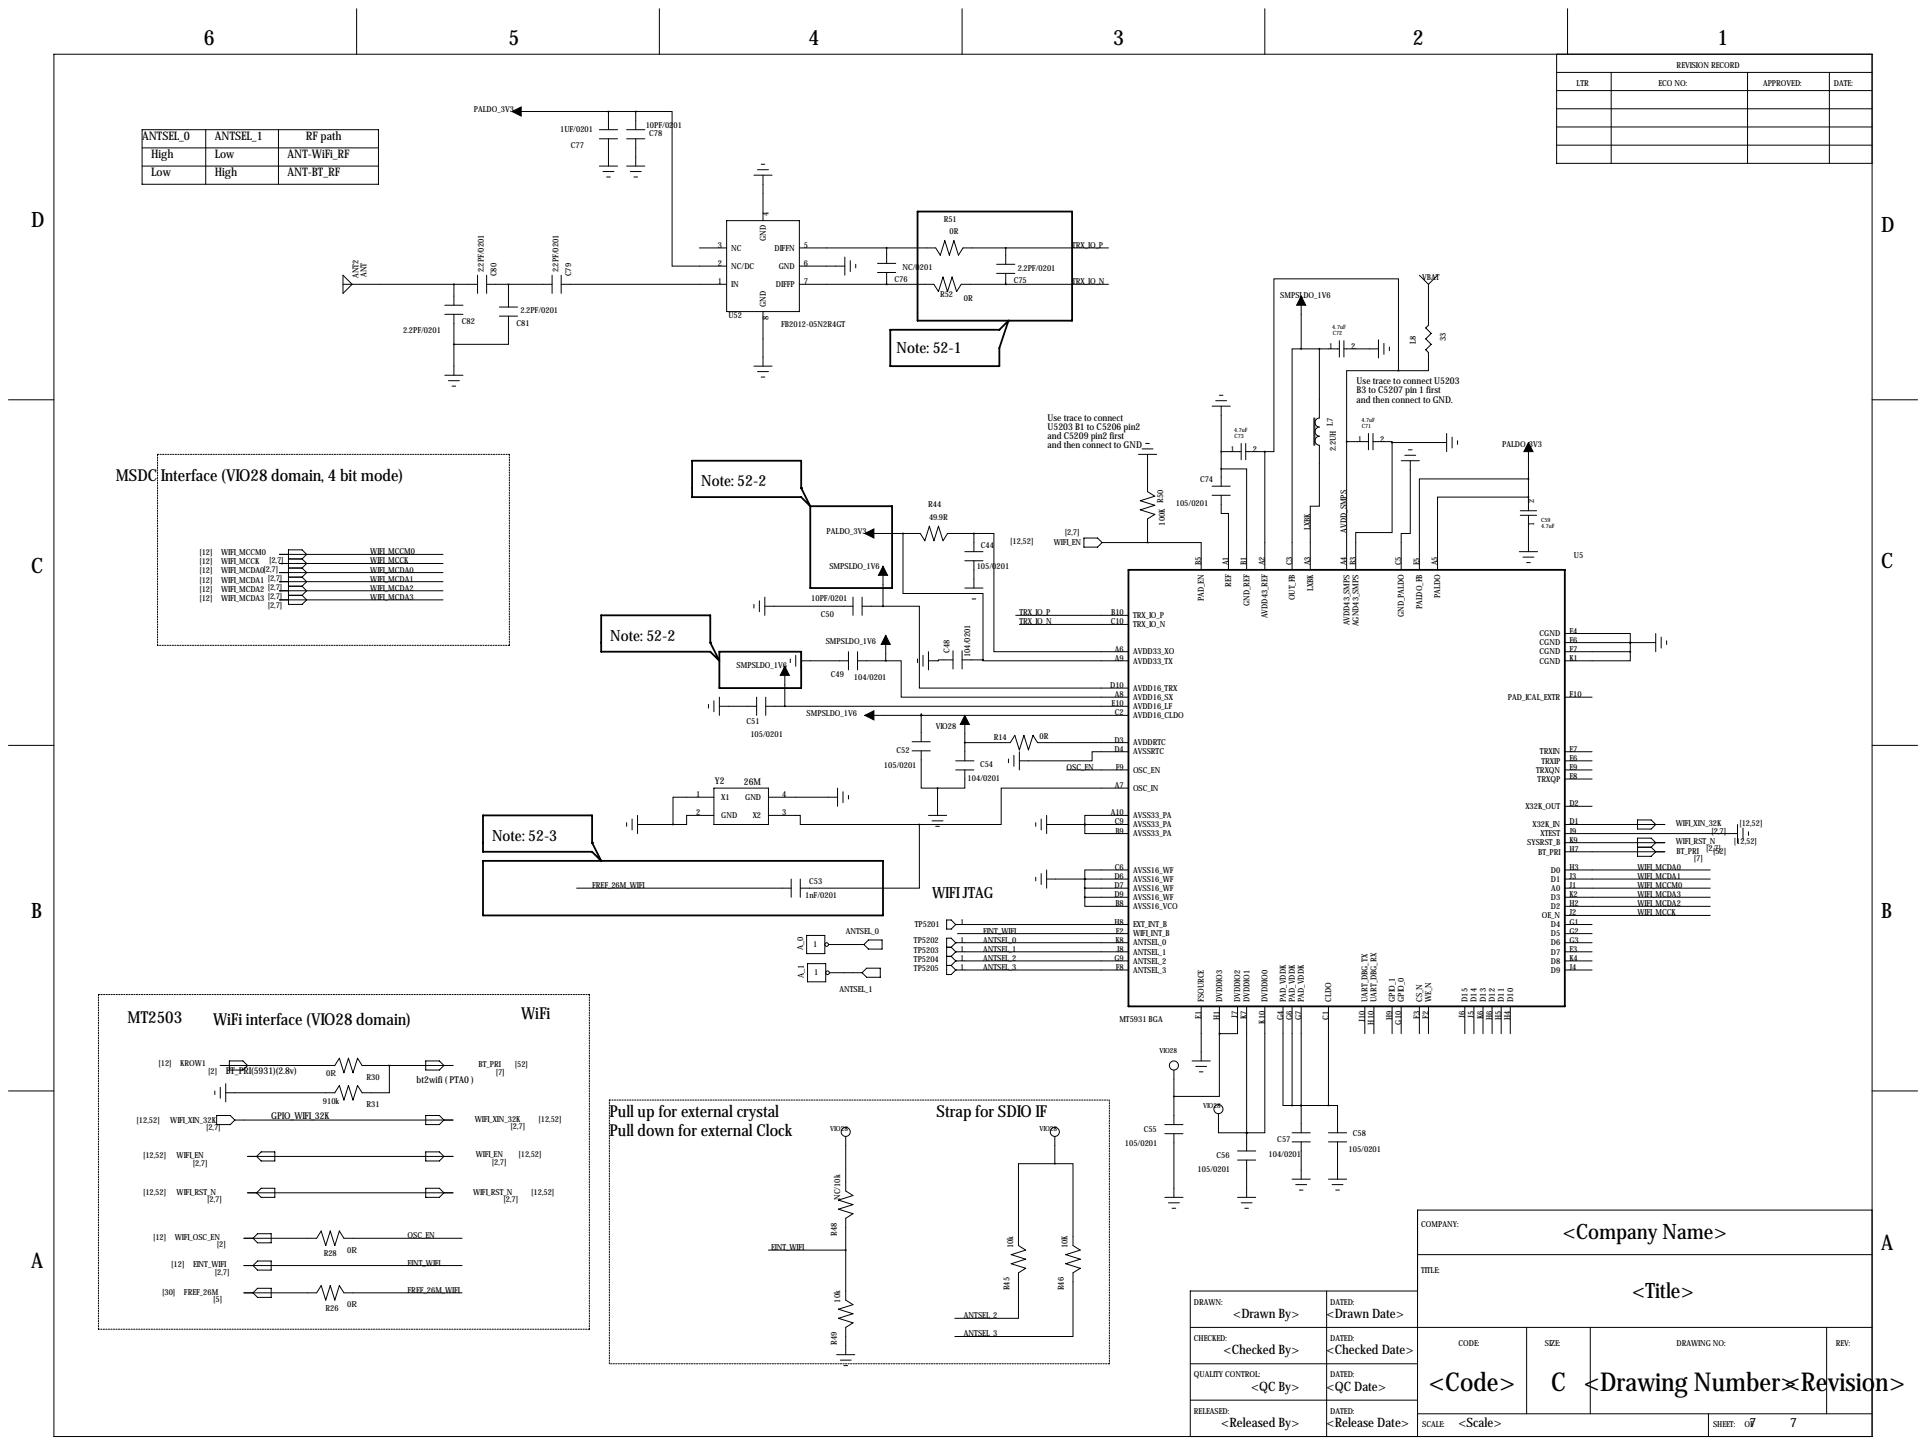
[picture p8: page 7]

ANTSEL_0 | ANTSEL_1 | RF path
High | Low | ANT-WiFi_RF
Low | High | ANT-BT_RF

Use trace to connect U5203
B3 to C5207 pin 1 first
and then connect to GND.

Use trace to connect
U5203 B1 to C5206 pin2
and C5209 pin2 first
and then connect to GND

MSDC Interface (VIO28 domain, 4 bit mode)

Pull up for external crystal
Pull down for external Clock

Strap for SDIO IF

DRAWN: <Drawn By> | DATED: <Drawn Date>

CHECKED: | DATED: | CODE: | SIZE: | DRAWING NO: | REV:

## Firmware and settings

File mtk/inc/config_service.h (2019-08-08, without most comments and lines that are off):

#define __CONFIG_SERVICE_H__
#include "gm_type.h"
#include "error_code.h"
#include "socket.h"
#include "gps.h"
#define VERSION_NUMBER  "1.0.26"
#define DEFAULT_DEVICE_TYPE "GW01H"
#define DEFAULT_SMS_PWD "GMGPS"
#define APN_DEFAULT "CMNET"
#define APN_USER_DEFAULT ""
#define APN_PWD_DEFAULT ""
#define GOOME_IMEI_DEFAULT "668613000000000"
#define GOOME_DEV_NUMBER_DEFAULT "13000000000"
#define UPDATE_OEM_CODE  "GOOME"
#define UPDATE_DEVICE_CODE "DEVICEID00001"
#define UPDATE_BOOT_CODE "FFFFFFFF"
#define CONFIG_GOOCAR_SERVER_ADDERSS   "gw01.szdatasource.com:8841"
#define CONFIG_LITE_SERVER_IP          "119.23.109.222"
#define CONFIG_GOOCAR_SERVER_IP        "54.222.183.200"
#define CONFIG_FACTORY_SERVER_ADDERSS  "factorytest.gpsorg.net:8841"
#define CONFIG_SERVER_ADDERSS          "config.gpsorg.net:39996"
#define CONFIG_SERVER_IP               "47.106.251.151"
#define CONFIG_AGPS_SERVER_ADDERSS     "agps.srv.gpsorg.net:8866"
#define CONFIG_AGPS_SERVER_IP          "119.23.109.222"
#define CONFIG_LOG_SERVER_ADDERSS      "firmwarelog.gpsorg.net:39998"
#define CONFIG_LOG_SERVER_IP           "47.106.251.151"
#define GOOME_UPDATE_SERVER_DNS        "firmware.gpsorg.net:39999"
#define GOOME_UPDATE_SERVER_IP         "47.106.251.151"
#define CONFIG_CMD_MAX_LEN         10
#define CONFIG_STRING_MAX_LEN      100
#define CONFIG_UPLOAD_TIME_MAX     10800ul
#define CONFIG_UPLOAD_TIME_DEFAULT 10
#define CONFIG_UPLOAD_TIME_MIN     3
#define CONFIG_SPEEDTHR_MAX        180
#define CONFIG_SPEEDTHR_MIN        5
#define GOOME_LITEDEV_DNS          ".gmiot.net"
#define GOOME_GPSOO_DNS            ".szdatasource.com"
#define GOOME_MAPS_URL_DEFAULT "http://ditu.google.cn/maps?q="
typedef enum
{
  EXTI_Trigger_Falling_Low    = (u8)0x00,
  EXTI_Trigger_Rising         = (u8)0x01,
  EXTI_Trigger_Falling        = (u8)0x02,
  EXTI_Trigger_Rising_Falling = (u8)0x03
} EXTI_Trigger_TypeDef;
enum
{
	TRG_FALL_LOW = EXTI_Trigger_Falling_Low,
	TRG_RISING   = EXTI_Trigger_Rising,
	TRG_FALLING  = EXTI_Trigger_Falling,
	TRG_RIS_FALL = EXTI_Trigger_Rising_Falling,
	TRG_NO_ONE
};
typedef enum
{
    CFG_SERVERADDR,           // 主服务器地址,xxx.xxx.xxx.xxx:port      = 0
    CFG_UPLOADTIME,           // 上传gps间隔
    CFG_APN_NAME,
    CFG_APN_USER,
    CFG_APN_PWD,
    CFG_DEVICE_NUMBER,
    CFG_OPEN_APGS,
	CFG_GPS_CLOSE,
	CFG_GPS_TYPE,
    CFG_GPS_UPDATE_TIME,
    CFG_CFGSERVERADDR,     //=70
    CFG_TEST_SERVERADDR,
    CFG_AGPSSERVERADDR,
    CFG_LOGSERVERADDR,
    CFG_UPDATESERVERADDR,
    CFG_UPDATEFILESERVER,
    CFG_MIN_SNR,
	CFG_REOPEN_GSP_TIME,
    CFG_SMOOTH_TRACK,
    CFG_CUSTOM_CODE,      //客户代码
    CFG_TERM_MODEL,       //终端型号ID
    CFG_TERM_VERSION,     //终端当前版本号     //100
    CFG_TERM_BOOT_CHECK,  //终端当前版本BOOT校验码
    CFG_TIME_ZONE,
    CFG_EXPMU_PWRON_CNT,
    CFG_TIMING_NUMBER,
    CFG_MTK_PWRON_CNT,
    CFG_WORK_MODE,
    CFG_POSITION_SOURCE,
    CFG_WORK_MODE_PARAM,
    CFG_APN_CHECK,
    CFG_WIFI_STATE,
    CFG_CHANG_PWD,
    CFG_PWR_REP_CNT,
    CFG_REP_GAP,
    CFG_SMS_PWD,
    CFG_LIGHT_STATE,
    CFG_STATIS_INFO,
    CFG_IS_TEST_MODE,
    CFG_DEV_TYPE,
    CFG_PARAM_MAX
}ConfigParamEnum;
typedef enum
{
    TYPE_NONE = 0x00,
    TYPE_INT = 0x01,
    TYPE_SHORT = 0x02,
    TYPE_STRING = 0x03,
    TYPE_BOOL = 0X04,
    TYPE_FLOAT = 0X05,
    TYPE_BYTE = 0x06,
    TYPE_ARRY = 0x07,
    TYPE_MAX
}ConfigParamDataType;
typedef enum
{
    CFG_CMD_REQ = 0x13,
    CFG_CMD_ACK = 0x92,
    CFG_CMD_RESULT = 0x14,
    CFG_CMD_MAX
}ConfigCmdEnum;
typedef enum
{
    CFG_CMD_REQ_ALL = 0x00,
    CFG_CMD_REQ_ONCE = 0x01,
    CFG_CMD_REQ_PERMANENT= 0x02,
}ConfigCmdReqType;
typedef enum
{
    HEART_SMART = 0x00,  //0x03 or 0x07
    HEART_NORMAL = 0x01,  //0x03
    HEART_EXPAND = 0x02,  //0x07
    HEART_MAX
}ConfigHearUploadEnum;
typedef struct
{
    ConfigParamDataType type;
    union
    {
        u8*  str;
        u32  i;
        u16  s;
        u8   b;
        float f;
    }data;
    u16 len;
} ConfigParamItems;
typedef enum
{
    PROTOCOL_NONE = 0x00,
    PROTOCOL_GOOME = 0x01,
    PROTOCOL_CONCOX = 0x02,
    PROTOCOL_JT808 = 0x03,
    PROTOCOL_2929 = 0x04,
    PROTOCOL_MAX
}ConfigProtocolEnum;
enum
{
    PLATFORM_LOC_MODE_WIFI = 0,   //WiFi定位
	PLATFORM_LOC_MODE_GPS = 1,   //GPS定位
    PLATFORM_LOC_MODE_LBS = 2,   //非GPS定位
	PLATFORM_LOC_MODE_INVAILD,
};
enum
{
	ALARM_CLOCK_MODE = 1,       // 闹钟模式 [一天之中哪个时间点起来,最多可以设置4个]
    FIX_FRQ_MODE = 2,           //
    TRACK_MODE = 3,             //定时模式     AppStu.WorkMode  [每隔多长时间起来.比如5分钟]
    WEEK_ALARM_MODE = 4,        //星期模式 [每个星期的星期几起来]
	PLATFORM_CYCLIC_MODE = 5,   //平台模式中的循环模式
	PLATFORM_TIMEPOINT_MODE = 6,//平台模式中的时间点模式
	WORK_MODE_INVALID,
};
typedef enum
{
    PWRALM_GPRS = 0,
    PWRALM_GPRS_SMS = 1,
    PWRALM_GPRS_SMS_CALL = 2,
    PWRALM_GPRS_CALL = 3,
}PowerAlarmMode;
typedef struct
{
	u32 day;
	u32 time_point;
}WeekkModeTimePointStruct;
typedef struct
{
	u32 time_point[4];
}ClockModeTimePointStruct;
typedef struct
{
	u32 interval;
}TrackeModeTimeValueStruct;
typedef struct
{
	u32 pos_mode;
	u32 loop_start_tim;
	u32 loop_interval;
	u32 loop_stop_tim;
}PlatLoopModeStruct;
typedef struct
{
	u32 pos_mode;
	u32 utc_time_point;
}PlatTimePiontModeStruct;
typedef union
{
	PlatTimePiontModeStruct plat_tp[3];
	PlatLoopModeStruct plat_loop;
	TrackeModeTimeValueStruct track;
	ClockModeTimePointStruct clock;
	WeekkModeTimePointStruct week;
}WorkModeParamUnion;
#define WORK_MODE_PARAM_LEN 24
#define MAX_SMS_PWD_LEN     11
#define MAX_DEVICE_STRING   10
GM_ERRCODE config_service_create(void);
GM_ERRCODE config_service_destroy(void);
GM_ERRCODE config_service_timer_proc(void);
void config_service_connection_ok(void);
void config_service_connection_failed(void);
void config_service_close_for_reconnect(void);
u16 config_service_get_length(ConfigParamEnum id, ConfigParamDataType type);
GM_ERRCODE config_service_get(ConfigParamEnum id, ConfigParamDataType type, void* buf, u16 len);
void config_service_set(ConfigParamEnum id, ConfigParamDataType type, const void* buf, u16 len);
void* config_service_get_pointer(ConfigParamEnum id);
ConfigProtocolEnum config_service_get_app_protocol(void);
ConfigHearUploadEnum config_service_get_heartbeat_protocol(void);
S8 config_service_get_zone(void);
bool config_service_is_main_server_goome(void);
bool config_service_is_alarm_sms_to_one(void);
u8 config_service_get_sos_number(u8 index, u8 *buf, u16 len);
bool config_service_is_agps(void);
GPSChipType config_service_get_gps_type(void);
GM_ERRCODE config_service_read_from_local(void);
GM_ERRCODE config_service_save_to_local(void);
const char * config_service_get_device_type(u16 index);
void config_service_restore_factory_config(bool is_all);
void config_service_set_test_mode(bool state);
bool config_service_is_test_mode(void);
bool config_service_is_default_imei(void);
GM_ERRCODE config_service_set_device_sim(u8 *pdata);
void config_service_change_ip(ConfigParamEnum idx, u8 *buf, u16 len);
void config_service_change_port(ConfigParamEnum idx, u16 port);
StreamType config_service_update_socket_type(void);
S8 config_service_get_zone(void);
void config_service_set_reming_gps_count(void);
StreamType config_service_agps_socket_type(void);

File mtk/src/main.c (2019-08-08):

/**
 * Copyright Goome Technologies Co., Ltd. 2009-2019. All rights reserved.
 * File name:        main.c
 * Author:           Chris.Lu     
 * Version:          1.0
 * Date:             2019-06-10
 * Description:      APP Main Function
 * Others:      
 * Function List:    
    1. APP
 * History: 
    1. Date:         2019-06-10
       Author:       Chris.Lu
       Modification: First version
    2. Date: 		 
	   Author:		 
	   Modification: 

 */

#include <gm_type.h>
#include <gm_timer.h>
#include <gm_uart.h>
#include <gm_system.h>
#include "main.h"
#include "error_code.h"
#include "utility.h"
#include "hard_ware.h"
#include "led.h"
#include "system_state.h"
#include "config_service.h"
//#include "g_sensor.h"
#include "uart.h"
//#include "watch_dog.h"
#include "log_service.h"
//#include "relay.h"
#include "gsm.h"
#include "sms.h"
#include "gps.h"
#include "gprs.h"
#include "expmu.h"
#include "auto_test.h"
#include "expmu_service.h"
#include "gm_app.h"
extern s32 TK_dll_set_sb(S32 val);
extern void app_main_entry(void);
extern void DLL_init_SB(void);

extern const s32 service_feature;
u32 dll_version=0;
u32 dll_edition=0;
s32 g_exportfunc[3]={0};

void Service_Entry(dll_struct* dll)
{
	TK_dll_set_sb(service_feature);

	dll_version = dll->header.version;
	dll_edition = dll->header.feature;
	dll->export_func_count = sizeof(g_exportfunc) / sizeof(g_exportfunc[0]);
	dll->export_funcs = g_exportfunc;
	
	dll->export_funcs[0] = (S32)DLL_init_SB;
	dll->export_funcs[1] = (S32)app_main_entry;
}


void DLL_init_SB(void)
{
	TK_dll_set_sb(service_feature);
}

void app_main_entry(void)
{
    //system ticks
	util_create();

     //uart model create
    uart_create();

    system_state_create();

    //Read current config para
    config_service_read_from_local();
    
    //GSM model create
    gsm_create();

    //gprs model create
    gprs_create();

    //sms model create
    sms_create();

    hard_ware_create();

    led_create();

    gps_create();

    expmu_create();

    //延迟10秒再开始自检，否则还没有获取到IMEI会误入自检
    #if 0 /*当前版本不进入自检*/
    if(GM_REBOOT_POWER_ON == system_state_get_boot_reason(false))
	{
		GM_StartTimer(GM_TIMER_SELF_CHECK_START, 30*TIM_GEN_1SECOND, timer_self_test_start);
		LOG(INFO,"It may enter self check 30 seconds later.");
	}
	#endif
	//g_sensor_create();
	GM_StartTimer(GM_TIMER_MAIN_UPLOAD_LOG, 2*TIM_GEN_1SECOND, upload_boot_log);


    GM_CreateKalTimer(0);
    
    GM_StartKalTimer(0, kal_timer_1s_proc, GM_TICKS_1_SEC);

    GM_StartTimer(GM_TIMER_10MS_MAIN, TIM_GEN_10MS, timer_10ms_proc);

    GM_StartTimer(GM_TIMER_1S_MAIN, TIM_GEN_1SECOND, timer_1s_proc);
    
}


//app main cycle
void timer_10ms_proc(void)
{
	GM_StartTimer(GM_TIMER_10MS_MAIN, TIM_GEN_10MS, timer_10ms_proc);

    expmu_service_timer_proc();

    expmu_timer_proc();
    
	led_timer_proc();

    //gsm_timer_proc();

    //g_sensor_timer_proc();
    gprs_timer_proc();

    uart_timer_proc();

}


void kal_timer_1s_proc(void* p_arg)
{
    util_timer_proc();

    system_state_timer_proc();

}


void timer_1s_proc(void)
{
    GM_StartTimer(GM_TIMER_1S_MAIN, TIM_GEN_1SECOND, timer_1s_proc);

    auto_test_timer_proc();
}

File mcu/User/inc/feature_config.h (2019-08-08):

/**
* Copyright (C), Goome Technologies Co., Ltd. 2009-2019. All rights reserved.
* File name : feature_config.h
* Author:  Version:	Date:
* Description: MCU chip define
* Function List:
* History:
  1.Date: 2019/6/6
    Author: Chris.Lu
    Modification: Created file
*/

#ifndef __FEATURE_CONFIG_H__
#define __FEATURE_CONFIG_H__

#include "stm8l15x_gpio.h"
#include "stm8l15x_exti.h"


#ifdef __STM8L151G6__

#define MODEL_POWER_CTRL_BASE GPIOB
#define MODEL_POWER_CTRL_PIN  GPIO_Pin_0

#define LIGHT_SENSATION_BASE  GPIOB
#define LIGHT_SENSATION_PIN   GPIO_Pin_3
#define LIGHT_SENSATION_EXIT  EXTI_Pin_3

#else

#define MODEL_POWER_CTRL_BASE GPIOB
#define MODEL_POWER_CTRL_PIN  GPIO_Pin_0

#define LIGHT_SENSATION_BASE  GPIOC
#define LIGHT_SENSATION_PIN   GPIO_Pin_7
#define LIGHT_SENSATION_EXIT  EXTI_Pin_7


#endif

#endif

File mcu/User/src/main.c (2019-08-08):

/**
* Copyright (C), Goome Technologies Co., Ltd. 2009-2019. All rights reserved.
* File name : main.c
* Author:  Version:	Date:
* Description:stm8l151g6 project main file
			  1,MCU主循环
* Function List:
* History:
  1.Date: 2019/4/9
    Author: Chris.Lu
    Modification: Created file
*/

#include "bsp.h"
#include "app.h"
#include "main.h"
#include "string.h"
#include "system_ticks.h"
#include "app_rtc_alarm.h"
#include "app_fram_manger.h"
#include "debug_port.h"

void main()
{
	send_event_to_main_hadle(EVENT_POWER_UP);

	while(1)
	{
		switch(get_system_event())
		{
			case EVENT_POWER_UP:

				/*BSP Init*/
				bsp_power_up_init();
				/*App Init*/
				app_power_up_init();

				send_event_to_main_hadle(EVENT_WAIT_LPM);

				set_wkp_reason(EVENT_POWER_UP);

                #ifdef _DEBUG_
                print("\r\nclock(%x) power up!\r\n",clock());
                #endif
                
				break;
			case EVENT_WAIT_LPM:

				app_wait_lpm_process();
				
				if(is_need_change_event_to_lpm())
				{
					send_event_to_main_hadle(EVENT_PREPARE_ENTER_LPM);
				}
				
				break;
			case EVENT_PREPARE_ENTER_LPM:

				app_enter_lpm_init();

                send_event_to_main_hadle(EVENT_ENTER_LPM);
				
				break;
			case EVENT_ENTER_LPM:
            
                #ifdef _DEBUG_
                print("\r\nclock(%d) system enter LPM!",clock());
                #endif

                app_para_write_to_fram();

				bsp_enter_lpm_init(BSP_LPM_L3);

				halt();

				bsp_exit_lpm_init(BSP_LPM_L2);

				app_fram_para_exit_lpm_init();

                #ifdef _DEBUG_
                print("\r\nclock(%d) System wake up!..\r\n",clock());
				#endif
                
				break;
				
			case EVENT_EXTI1_WKP:
				
				exit_lpm_from_exti1_process();

				break;
			case EVENT_EXTI2_WKP:

				exit_lpm_from_exti2_process();
				
				break;
			case EVENT_RTC_WKP:
				
				exit_lpm_from_rtc_alarm_process();
				
				break;
			case EVENT_EXIT_LPM:

				bsp_exit_lpm_init(BSP_LPM_L0);

				app_exit_lpm_init();

				send_event_to_main_hadle(EVENT_WAIT_LPM);

				break;
			default:
				/*异常事件，等待看门欧复位*/
				break;
		}

	}
}

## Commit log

2019-08-08 init version
    [stvp_download.stp, 功能特性说明.xlsx, 无线设备指令表.xls]
2019-08-08 添加硬件设计资料
    [GW01_贴片BOM_V1.6(不带WIFI不带GSENSOR) 开源.xls]
